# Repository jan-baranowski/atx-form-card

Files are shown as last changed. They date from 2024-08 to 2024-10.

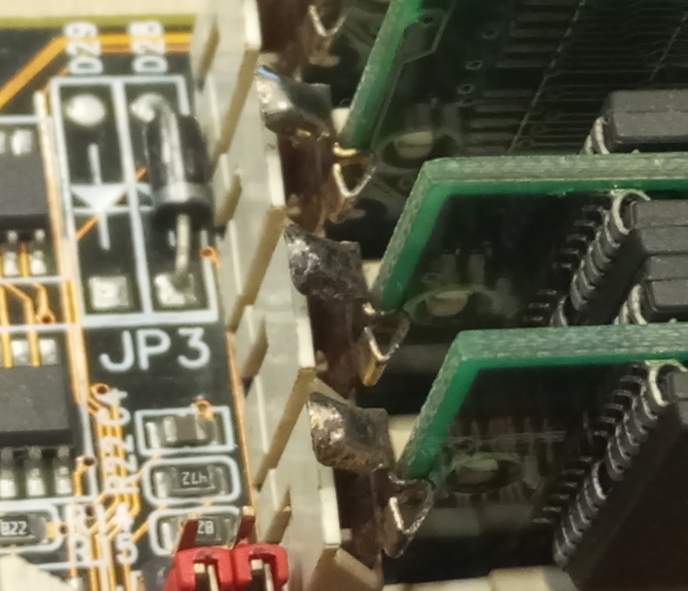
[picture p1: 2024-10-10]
doc/blogpost/img/IMG_20241010_175703.jpg

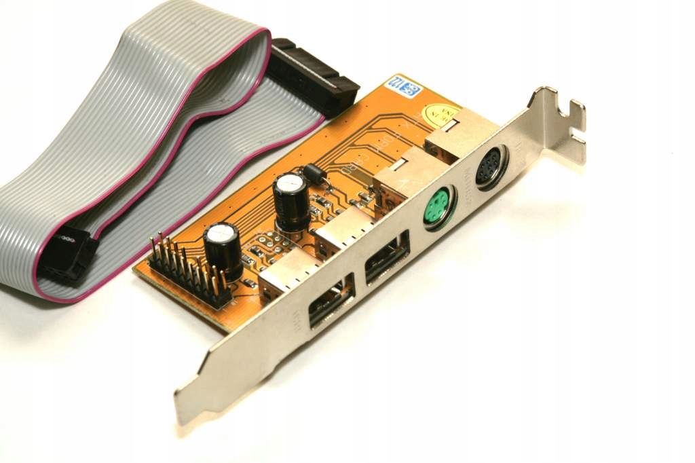
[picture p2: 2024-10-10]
doc/blogpost/img/06745c53491888d843a4edbb89a4.jpg

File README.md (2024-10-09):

ATX Form Card
=============

This is the repo containig project files, production files and documentation for an ATX Form Card - USB+IrDA+PS/2 bracket to be used in late AT motherboards produced by PCChips and ASUS ca. 1997.

Complete description of this project can be found at https://patoelektronika.blogspot.com/2024/10/atx-form-card.html

All the work that is not a third party documentation or libraries is licenced under WTFPLv2.

Third-party items incorporated
------------------------------

1. ATX Form Card reverse engineering attempt by Jacek Głogowski - /doc/glogowski.pdf - https://jacek.unixstorm.org/elektronika/atx-form-card.html
2. mini DIN EAGLE library - /hw/atx_from_card/mini_din.lbr - https://forums.parallax.com/discussion/124010/what-is-the-ps2-connectors-name-in-the-eagle-lib
3. polygon version os Open Source Hardware logos library for EAGLE - /hw/atx_from_card/oshw_custom.lbr - Andrew Cooper, http://www.darkerview.com
4. documentation on using HP C4103a IR transceiver with ASUS motherboards - /doc/irda/* - http://www.colin99.co.uk/extras/irda/hp_c4103a_irda.htm and https://www.infrarotport.de/mobo/asus_ir.htm
5. documentation on audio bracket, a companion to ATX Form Card - /doc/25-pin-sound-game-ribbon-cable - https://retrocomputing.stackexchange.com/questions/25069/25-pin-sound-game-ribbon-cable

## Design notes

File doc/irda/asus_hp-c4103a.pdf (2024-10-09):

Diese Seite führt da weiter, wo die Anregungen von Andreas Schüßler (https://www.infrarotport.de/mobo/asus_ir.htm) endeten.

Anschlußbelegung der ASUS-Infrarotschnittstellen und des IrDA-Moduls (C4103A) von Hewlett-Packard.

Die meisten Asus-Boards sollten folgenden Pfostenstecker aufweisen (verbindlich getestet mit P5A und P2B):

Den Anschluss FIR-RxD können wir zu diesem Zwecke getrost vergessen.

Daniel Eggel hat etwas intensiver geforscht und im Web bei HP die Belegung des HP-Steckers gefunden: HP-C4103A (https://www.infrarotport.de/mobo/c4103A2.PDF) (Stammt ursprünglich von folgender Seite: Hewlett-Packard). (http://www.hp.com/)
Steckerbelegung von vorne, also nicht die Lötseite!
PIN Number | Signal Name
1 (Indicator LED) | -SIGNAL_DETECT
2 (single-ended signal) | -RX_SIR
3 (Differential data) | -TX (Transmit Data)
4 (Ground) | PWR_GND
5 (FIR differential data) | -RX_FIR
6 (Differential data) | +TX (Transmit Data)
7 (5 volt power) | +5V_POWER
8 (FIR differential data) | +RX_FIR

Diese Pinbelegung ist offensichtlich nicht kompatibel zu einer bereits vorhandenen 8poligen ASUS-Standard-Buchse! (Erinnern wir uns an die mahnenden Worte von Andreas Schüßler). (https://www.infrarotport.de/mobo/asus_ir.htm)
Schließt man die HP-IrDA C4103A an das ASUS-Board an, so brennt sofort die Sicherung auf der Buchsenplatte durch. Zum Glück ist da eine drauf! Denn die Betriebsspannung von 5V wird mal eben kurzgeschlossen.

Dies bedeutet also Lötkolben anwärmen und umlöten (Lötkolben wird sowieso noch gebraucht)!

Leider besitze ich noch keine solche Buchse zum selbstlöten, weshalb ich auf ne fliegende Verkabelung ausgewichen bin. Hier aber ein paar Buchsen (incl. Herstellerbezeichnungen), gefunden auf den Seiten der Infrared Data Association: (http://www.irda.org/standards/pubs/IrDA_Dongle_V1p2.PDF)

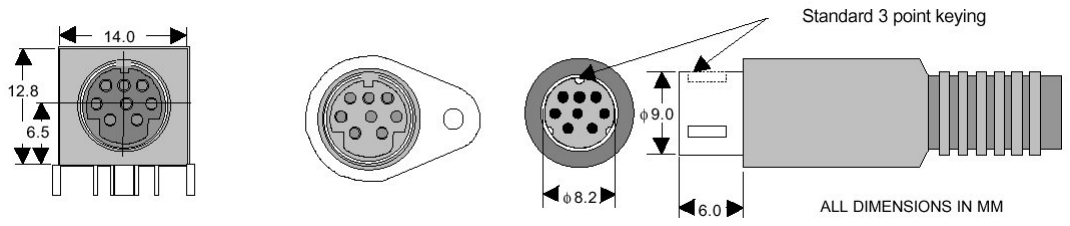
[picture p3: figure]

AMP | 750338-1
Maxconn | MMDV-8
Singatron | YE-1368A
CUI Stack | SD-80SN

Mit diesem Wissen bewaffnet, funktioniert die ganze Geschichte aber leider noch nicht ganz.
Der Rechner erkennt zwar (richtigen Anschluss vorrausgesetzt), dass etwas empfangen werden soll, jedoch kann der Rechner selbst nichts senden.
Schuld daran sind die differential TX Anschlüsse (RX ist single-ended) des HP Modules.
Die Asus-Boards können TX und RX leider nur single-ended.

Dadurch lassen wir uns aber nicht abschrecken.

Nach einigem Probieren studierte ich Dschen Reinecke's (https://www.infrarotport.de/ir-modul.HTML) Bauanleitung, was mich dazu bewog, den im HP-Modul eingebauten IR-Transceiver (HSDL-1100) genauer unter die Lupe zu nehmen.

Fündig geworden bin ich bei Agilent Technologies Inc. (http://www.semiconductor.agilent.com/ir/hsdl1100.html)

HP-IrDA C4103A an Asus Mainboards Infrarotprojekt | https://www.infrarotport.de/mobo/asus_hp-c4103a.htm
1 z 2 | 09.10.2024, 17:49

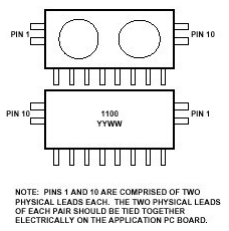
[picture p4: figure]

Pin | Description | Symbol
1 | PIN Bypass Capacitor | CX1
2 | Ground (Analog) | GND
3 | Averaging Capacitor | CX4
4 | Supply Voltage | VCC
5 | Receiver Data Output – Channel B | RXD-B
6 | Ground | GND
7 | Transmitter Data Input | TX
8 | Receiver Data Output – Channel A | RXD-A
9 | Threshold Capacitor | CX3
10 | LED Anode | LEDA

Pin 7 bietet ein single-ended TXD, was also lag näher, als diesen Pin mit dem entsprechenden Pin auf dem Mainboard zu verbinden.

Man nehme einen feinen Kreuzschlitz Schraubendreher und öffne das HP-Modul.
Von dem HP-Modul sind mir 2 verschiedene Varianten untergekommen, eines ist mit 4 Schrauben, das andere nur mit 2 Schrauben verschraubt. In jedem Fall muss der Aufkleber auf der Unterseite entfernt werden, darunter findet man 2 Schrauben.
Bei dem 4 Schrauben Modell befindet sich jeweils noch eine Schraube unter den kleinen runden Gerätefüssen.

Legt das Modul so vor Euch hin, dass der Transceiver zu Euch zeigt, das Anschlusskabel von Euch wegzeigt.

Nunmehr eine kleine Drahtbrücke zwischen Pin 7 des IR-Transceivers und der Anschlussleitung ganz links (meist rosa)
einlöten, Modul wieder zusammenschrauben!
Damit steht uns an Pin 1 des Steckers das single-ended TX-Signal zur Verfügung.

Jetzt noch das Anschlusskabel des IR-Modules mit der Pfostenleiste des Mainboards verbinden (bei mir in fliegender Verkabelung). .
Mainboard | 8poliger Stecker am HP-Modul
+5 Volt | Pin 7 (VCC)
IR-RxD | Pin 2 (-RX_SIR)
GND | Pin 4 (GND)
IR-TxD | Pin 1 (-SIGNAL_DETECT)
Die Anschlüsse für Fast-Infrared, sowie die differential bleiben jeweils frei.

Viel Spass beim Nachbau!
Fragen per Mail an mich.
Ach ja, keinerlei Garantie für evtl. Hardwareschäden!!!!!!
HP-IrDA C4103A an Asus Mainboards Infrarotprojekt | https://www.infrarotport.de/mobo/asus_hp-c4103a.htm
2 z 2 | 09.10.2024, 17:49

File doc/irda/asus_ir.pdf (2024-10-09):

# Willkommen, Bastler!

Diese Seite setzt auf das dankenswerterweise von Dschen Reinecke (https://www.infrarotport.de/kontakt.HTML) entwickelte und ins Netz gestellte Infrarotport-Selbstbauprojekt (http://www.infrarotport.de/) auf. Genaugenommen ist diese Seite nichts anderes, nur für ein ASUS-Motherboard (http://www.asus.com/) TX97-E durchgespielt. Diese Seite wurde wegen einiger Problemchen bei der Inbetriebnahme am Asus-Board erstellt.

Gemeinerweise | unterscheidet | sich | die
Anschlußbelegung | einer | | ASUS-

## Infrarotschnittstelle von der einer Hewlett-

Packard.

Nochmal für alle:

## Do not connect an HP C4103A directly to any ASUS mainboard!!! If you want to do so, look at the pages of Ralf Probst. (https://www.infrarotport.de/mobo/asus_hp-c4103a.htm)

Schließt man die HP-IrDA C4103A an das ASUS-Board an, so brennt sofort die Sicherung auf der Buchsenplatte durch. Zum Glück ist da eine drauf! Denn die Betriebsspannung von 5V wird mal eben kurzgeschlossen.
Update 1:
Daniel Eggel hat etwas intensiver geforscht und im Web bei HP die Belegung des HP-Steckers gefunden:
HP-C4103A (https://www.infrarotport.de/mobo/c4103A2.PDF) (Stammt ursprünglich von folgender Seite: Hewlett-Packard (http://www.hp.com/) ).

Das Board TX97-E von Asus ist serienmäßig für eine IrDA-Schnittstelle (http://www.irda.org/) vorbereitet. Sie kann auf 2 Arten angeschlossen werden:

1.: Mit dem Original - PS/2 Mouse, USB, Infrared Connector von ASUS, kostet etwa 35,-- euro.

Dies ist ein Slotblech mit einem Stück Leiterplatte, auf der die o.g. Buchsen montiert sind. Es wird wie ein normales Slotblech in den PC geschraubt. Ein mitgeliefertes Flachkabel mit Stecker paßt genau auf die Schnittstelle neben dem obersten PCI-Steckplatz. Eine der Buchsen darauf ist die IR-Buchse, die wie folgt beschaltet ist:

Asus TX97-E Infrarotprojekt von Andreas Schüßler | https://www.infrarotport.de/mobo/asus_ir.htm
1 z 3 | 09.10.2024, 17:48

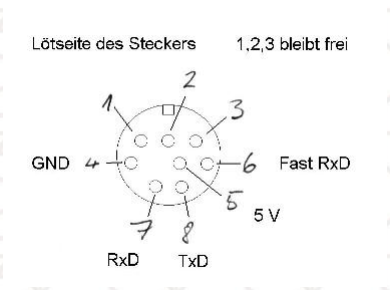
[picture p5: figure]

2.: Direkt auf einem der beiden Pfostenstecker. Hier ist der dargestellt, der der Vorderseite des Rechners zugewandt ist.

Die Anschlüsse für Fast-Infrared bleiben jeweils frei.

Die Datenübertragung über IrDA ist eine serielle. Das ASUS-Board TX97-E benutzt dafür den UART2-Baustein. Das muß im Bios (bei mir ist es das Award Bios v4.51PG) eingestellt werden:

Mit Del bzw. Entf während des Systemstarts ins Bios gehen, dort zur Seite CHIPSET FEATURES SETUP wechseln. Die seriellen Ports habe ich folgendermaßen konfiguriert:

ONBOARD SERIAL PORT 1 3F8H / IRQ 4
ONBOARD SERIAL PORT 2 2F8H / IRQ 3
UART2 USE INFRARED ENABLED

Die Infrarotschnittstelle läßt sich nur auf COM 2 legen. Der ONBOARD SERIAL PORT 2 darf daher nicht disabled werden. Die COM 2-Schnittstelle steht also ab jetzt nicht mehr zur normalen Verfügung.

Nun folgt die Installation im Betriebssystem, wie bei Dschen Reinecke (http://www.infrarotport.de/) beschrieben.

Wenn das alles erfolgreich war, kann man sich an den Aufbau wagen.

Ich mußte einen unverhältnismäßigen Aufwand in Sachen Abschirmung treiben. Abgeschirmtes Kabel, Siebung der Betriebsspannung (siehe Troubleshooting-Seite von Dschen Reinecke) (http://www.infrarotport.de/troubleshooting.HTML) und ein abgeschirmtes Gehäuse waren notwendig. Das festzustellen war das eigentliche Problem. Riesige Störungen entstanden durch bloßes Annähern an den IrDA-Baustein. Die Störungen kann man aber nur mit einem Oszilloskop feststellen. Dazu muß man wissen, daß das Sendesignal auf der TxD-Leitung High-aktiv ist, das Empfangssignal auf der RxD-Leitung dagegen Low-aktiv. ;-) Beides sind TTL-Pegel. Das Verbinden von TxD und RxD bringt also anders als bei einer normalen Schnittstelle in einem Terminalprogramm kein Echo hoch.
Update 2:
Mittlerweile weiß ich, woher die massiven Einstreuungen kommen: Eine unglaublich vermurkste Netzspannung bei mir im Haus. Mit Sinusform hat das wenig zu tun. Außerdem kann ich zwischen dem PC-Gehäuse und der Heizung einen Tauchsieder betreiben...

Ich wünsche allen viel Erfolg beim Nachbau! Bei Fragen zu DIESEM AUFBAU stehe ich gerne per email an Andreas Schüßler zur Verfügung. Alternativ kann auch Dschen Reinecke per Mail (https://www.infrarotport.de/kontakt.HTML) kontaktiert werden.
Wer Fragen dazu hat, wie man ein HP C4104A doch an ein ASUS-Bord anschliesst, wende sich an Ralf Probst. (http://www.infrarotport.de/mobo/asus_hp-c4103a.htm)

Update 3:
Disclaimer (oder wie das heisst):
Ach ja, sollte sich irgendjemand wegen dieser Seite auf den Schlips getreten fühlen, möchte er sich bitte mit MIR und nur mit MIR in Verbindung setzen. Selbstverständlich gehören Markennamen dem jeweiligen Eigentümer, es liegt mir fern, daran zu kratzen. Im Falle von Unterlassungsklagen oder Ähnlichem: Ich bin Student, bei mir ist nichts zu holen.

Update 4:
Mittlerweile bin ich kein Student mehr, zu holen ist aber trotzdem nix.

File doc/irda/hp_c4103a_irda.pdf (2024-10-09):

# Convert an HP C4103A Infra red module for use as a PC IrDA

port.

The C4103A infra red module is intended for adding IrDA communications to certain Hewlett Packard printers which don't already have this facility built into them. These modules are often left lying around the office unused, and as such can be picked up for next to nothing and slightly modified to act as an IrDA port for your PC. It will only be of use if your motherboard has a IrDA connector, which most do.

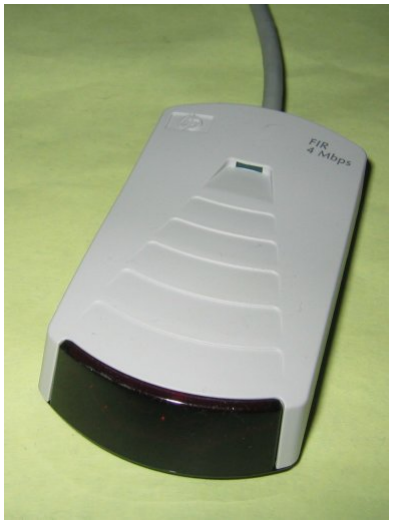
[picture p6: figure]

I take no credit at all for the technical aspects of working out the necessary modifications, they are all down to the following two web pages:

http://212.188.112.5/kengaru/index.php

http://www.infrarotport.de/mobo/asus_hp-c4103a.htm

Now unless you are very good at German and Russian, you will have spotted the problem with those pages. So I am simply setting out what you need to do to achieve the result of being able to use the C4103A module with a standard modern motherboard which has an IrDA connector. I recommend looking at the above two pages for extra information which I don't necessarily supply here. The latter one will go through the Google translator to give a fairly readable page. (http://216.239.35.120/translate_c?hl=en&sl=de)

Typically, the connector will have the following pinout. This certainly applies to Asus and Abit motherboards, so is likely to be reasonably standard:

The cable of the HP C4103A is an 8 pin mini-Din connector, and has most of the functions we require, but not the single ended TxD (transmit data) required:

Pin Number | Signal Name | Typical wire colour
1 | (active high input) -SIGNAL_DETECT | Pink
2 | (single-ended driver) RX_FIR | Green
3 | (TP, pins 3 and 6) -TX (Transmit Data) | Light blue
4 | (TP, pins 4 and 7) PWR_GND | Yellow
5 | (Receive Data Gnd) -RX_FIR | White
6 | (pulse = data 0) +TX (Transmit Data) | Orange
7 | +5V_POWER | Purple
Convert an HP C4103A Infra red module for use as a PC IrDA port | http://www.colin99.co.uk/extras/irda/hp_c4103a_irda.htm
1 z 5 | 09.10.2024, 17:53

8 | (pulse = data 0) +RX_FIR | Black

8 Pin Mini-Din Plug

This is the plug pin view of the mini-Din plug.

2 | 1
+ | +
5+ +4 | +3
| + + + 8 7 6

As the above web links show, we need to make a small wiring change to add the required signal, from a point connected to pin 7 of the IR transceiver unit, to the pink wire from the unit. The first, surprisingly tricky thing to do is open the C4103A unit. There are probably four screws holding it together, though you won't see any of them! Two hide under the small rubber feet at the cable end of the module, the other two under the large black label in very offset positions.

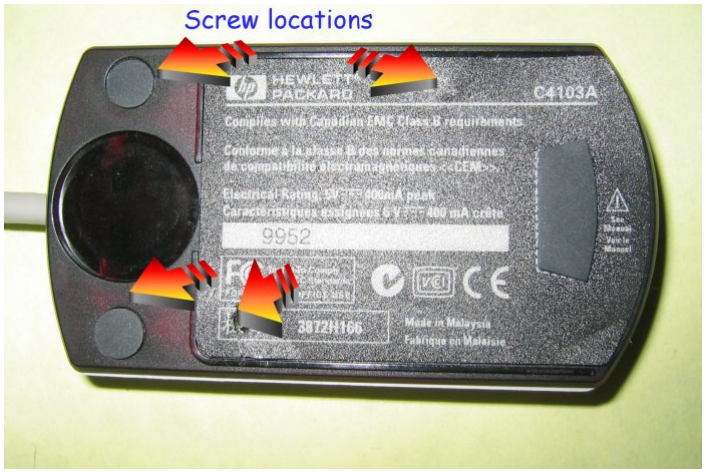
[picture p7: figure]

Remove these, take the unit apart, carefully noting how the cable support has notches in one side which sit in grooves of the case when re-assembled. Some units have different screw positions and quantities, some have different wiring colours, and some have a different PCB payout such that you may need place your wire in a different position (see later).

Solder a wire as shown, from the resistor RX1 (end towards IR module):

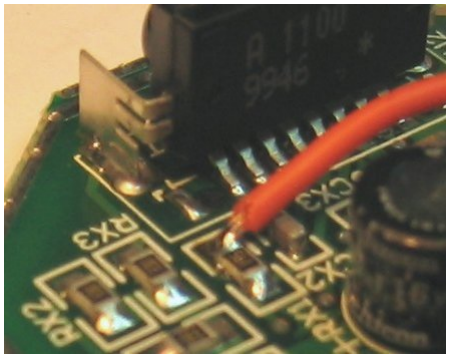
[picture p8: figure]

Run the wire down to the underside of the PCB, connector pin1 (typically a pink wire). If you wish to carry on also using the module for its intended application with HP printers, you should find space to fit a small toggle switch so that you can isolate the new wire. Most people don't wish to do this and simply run the wire as shown:

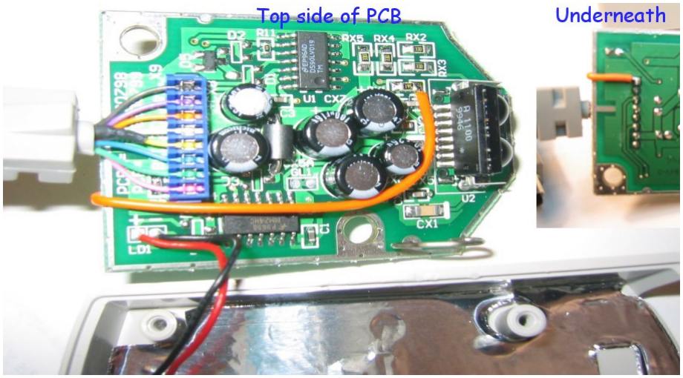
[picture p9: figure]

We have not disconnected the existing circuitry connected to pin 1 of the PCB. Since this is an input to the green LED on the HP C4103A, we are allowing this LED to illuminate whenever data is transmitted.

Here we have an alternative version of the module. It has only 2 screws (under the info label at exact same spots as the version above), no foil shielding, and the PCB has a different layout. The mod is to solder a wire (here a white one) from the RX1 resistor (at the side of the IR transceiver) to PIN 1 of the JP2 header (which is marked with a white square). Information kindly supplied by "fossalta (at) xs4all (dot) nl".

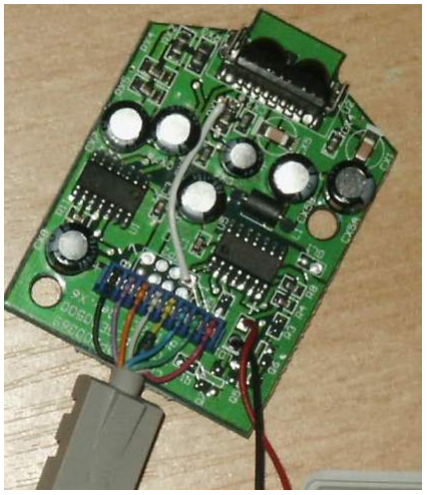
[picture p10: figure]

Reassemble the unit. Now you have the problem of connecting to the motherboard. You have a choice here. You can buy a 8 pin mini-Din panel mount socket from RS Components etc, and carefully mount this into a blanking plate for the back of your computer. Then wire the pins thus, from a 5 pin female header connector to the back of the 8 pin mini-Din socket:

Mini Din Pin Number | Signal Name | Motherboard header pin
1 | Now our TxD pin | 5
2 | Rxd | 3
3 | | -

4 | GND | 4
5 | | -
6 | | -
7 | +5V_POWER | 1
8 | | -

RS Components (http://www.rswww.com/) do the sockets, in multiples of 5, part number 183-1805, and pins for them are 183-1811 in multiples of 10. If, like me, you thought it too expensive to source an individual 8 pin mini-Din socket, then use an alternative connector. I chopped off the 4103A plug, and wired it instead to a 9 pin D connector plug, pin for pin, and also connected the cable screen to the plug body. I then found a scrap ISA card with a convenient end plate already punched out for this size of connector, i.e. an old graphics card. I stripped off the PCB leaving me with just the end panel, onto which I fitted a 9 pin D connector socket, and performed the same wiring as above.

My first attempt at making it run was a flop, because Abit didn't make it terribly obvious which was pin 1 of the IrDA connector. Once this was correct, we could start on the software. I told the BIOS to enable the IrDA port as HPSIR rather than ASKIR (latter didn't work). This also had the unfortunate consequence of disabling the COM2 serial port. Then I let Windows XP detect the IR port. Now if I put my horrible little Compaq LTE5100 laptop in front of the HP C4103A module, the green light on the module would flash, and the two machines announced that they were within range of each other ("Colin's laptop is in range" and "Colin's XP1600 is in range", which are the machine names).

Settings

I came unstuck in terms of real data transfer between the two at this point, because XP can only install a network with another PC which runs Windows 98 SE or later, and my old laptop was stuck on Windows 95 SE due to a lack of memory. No doubt I could install the necessary networking manually on the laptop but that was starting to be hard work. The laptop however can also print to my HP Laserjet 6P printer via IrDA, and program a Nokia 5210. But when the printer was put in front of the C4103A, though the LEDs flashed, Windows XP did not report hardware was in range. Neither would Windows XP see the Nokia phone. So ultimately, though I had got the system to work to some extent with the laptop, I was unable to get the important stuff to work. Perseverance paid off though, I went back to PC's setup BIOS and selected Half Duplex type HPSIR, and hey presto, communications were established with Nokia 6100 and 5210 phones. Limiting connection speed to 19200baud in Windows XP settings helped reliability hugely. So in conclusion, I would recommend using the following parameters:

Setting type | Version I had | Value | As opposed to
BOIS setting: IR port | Abit / Award | HPSIR | ASKIR
BIOS setting: Duplex | Abit / Award | Half Duplex | Full Duplex
Windows Irda port setting: Maximum connect rate | Windows XP | 19200 baud | 115200

A reader of this article told me: "The device worked. My BIOS setting was set to IrDA, as ASKIR did not work. I don't have a setting for half duplex/full duplex. Not only that, the connect rate worked on 115200, 57600 and 19200 baud. I used Logomanager to upload logo, ringing tone and screensaver on my Nokia 5210 using the different baud mentioned. My system is ECS K7S5A motherboard, AMD Athlon 1000, Windows XP."

Another reader reported "In the BIOS I have the following options: RxD/TxD = Hi/Lo , Rx/Tx= Lo/Hi , Rx/Tx=Lo/Lo and Rx/Tx=Hi/Hi. It only works with setting Rx=Lo" So different settings are worth experimenting with if you find that communications are unreliable or you get strange errors. Another reader says "It works at 115200 bps on a Asus A7V333, Windows XP".

Another reader again, uses one with the following motherboard: MSI K7N2 Delta. Settings:
UART mode - IrDA
RxD/ TxD - Lo, Hi
IR Transmission Delay – Disabled
UR2 Duplex - Half
Use IR pins - IR-Rx2Tx2
Speed (WinXP) - 19200
Works great with Nokia 6200 with its transfer software

Another reader had a problem with the adapter getting hot, but found a solution in the BIOS: "In my award bios there's an entry : TX,RX Inverting Enable, with 4 options [no-no; no-yes; yes-no; yes-yes]. RX MUST be set to yes to let adapter work on winXP. What I have found is that when RX inverting is enabled, the adapter works the same way it does when is not enabled, BUT the irda bulbs get very very warm. So,bios settings for me are NO-YES It's a terrible AZZA 694TXL :) I use it for ordinary work, P3 600 Mhz (socket 370) 2x256 ecc sdram On winXp sp2 I can make the adapter work at 57600bps (!) In bios, HPSIR and HalfDuplex as you suggested on your webpage "

For now, I hope you find this information helpful. DISCLAIMER: Colour codes shown may vary. No responsibility is accepted for any damage caused, if you wish to try this experiment then it is entirely your own responsibility. You will need to be competent at soldering and fine work. THIS INFORMATION IS SUPPLIED AS-IS, NO RESPONSIBILITY IS ACCEPTED FOR ANY CONSEQUENTIAL DAMAGE, LOSS, INJURY OR MISHAP, HOWEVER CAUSED. Do not start to dismantle any equipment unless you are certain you are capable and have an understanding of electrical safety.

USB

I've had a number of emails asking if the HP C4103A module could be adapted for use with USB, and I have to say that this really would be far too much like hard work. Instead, buy a ready-built USB to IrDA adaptor from the good people at SVP communications, (http://svp.co.uk/products-solo.php?pid=404) for around

£12.69, their part number "5055", I use one of these with my latest laptop.

SVP
Communications
- The Shop (http://www.svp.co.uk/)

Colin McCormick, colin99@bigfoot.com September 2006.

Back to my web pages. (http://www.colin99.co.uk/)

Total site visitors since Jan 2005:

## See my video to DVD copy service, offering

transfers of Betamax, VHS, S-VHS, Video2000,Video8, Hi8, Digital8,

## miniDV,micromv, Betacam, N1500, N1700 and more: www.video99.co.uk

## The most affordable and flexible video tape to DVD transfer service in the UK. A personal service by an engineer with years of video

experience.

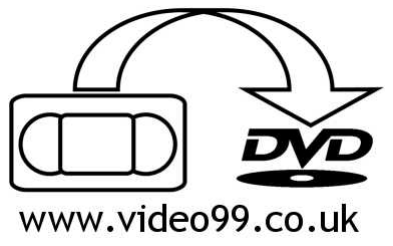
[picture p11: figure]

Sponsored links:

Ustawienia dotyczące prywatności i plików cookie
Zarządzana przez Google. Zgodność z zasadami TCF organizacji IAB. ID plaormy: 300

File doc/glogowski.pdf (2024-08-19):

## Schemat ATX FORM CARD do płyt głównych PC CHIPS

Poniżej zamieszczam schemat ideowy dodatkowego śledzia do płyt głównych PC CHIPS. Bardziej znana nazwa to ATX FORM CARD. Na ślediu tym znajdują się dwa porty USB, port PS/2 dla myszy i coś podobnego do PS/2 ale dla IRDY. Zamieściłem ten schemat ze względu na to, iż nie jest go łatwo znaleźć (ja nie znalazłem) a niektórzy (np. ja) posiadają jeszcze takie płyty i chętnie dodali by do nich wymienione powyżej porty. Wbrew pozorom łatwo zrobić taką karte nawet na tzw. pająka. A wygląda to tak.

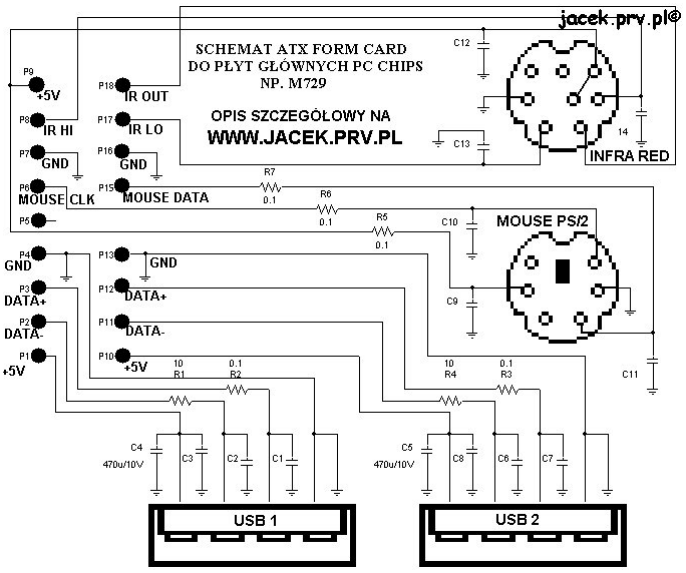
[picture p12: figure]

Na pierwszy rzut oka schemat może trochę przestraszyć (szczególnie jeśli nie interesujesz się zbytnio elektroniką), lecz tak naprawdę to tylko odpowiednio poprowadzone kabelki i już. Jeżeli chcemy to możemy praktycznie pominąć wszystkie elementy elektroniczne (rezystory i kondensatory), ale musimy liczyć się z tym, że może to się odbić na niezawodności i bezpieczeństwie dla układów na płycie głównej. Tak więc warto włożyć ciut więcej pracy i wykonać to tak jak na oryginalnej karcie (bo na niej się wzorowałem). Potrzebujemy do tego 2 kondensatory elektrolityczne 470u/10V, 13 kondesatorów ceramicznych o pojemności około 56p, 2 rezystory 10 Ohm i 5 rezystorów 0.1 Ohm. Najprościej mówiąc kondesatory filtrują i stabilizują a rezystory zabezpieczają przed zbyt dużym prądem. To teraz najgorsze, jak to wszystko połączyć i gdzie to podłączyć. Żeby było łatwiej będe umieszczał schemat ideowy a tuż pod nim zdjęcie jak to wygląda na "żywca". A więc cały ten schemat ideowy to jest to coś

Jacek Głogowski - strona prywatna | https://jacek.unixstorm.org/elektronika/atx-form-card.html
1 z 3 | 16.08.2024, 01:21

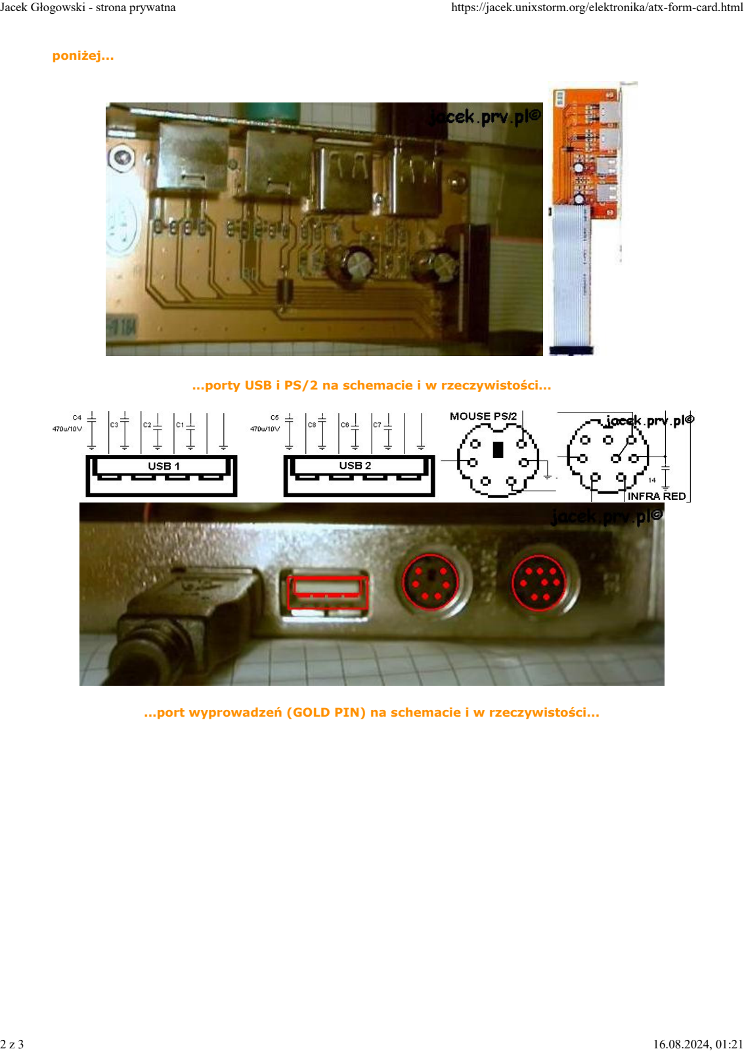
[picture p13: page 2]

poniżej...

...porty USB i PS/2 na schemacie i w rzeczywistości...

...port wyprowadzeń (GOLD PIN) na schemacie i w rzeczywistości...

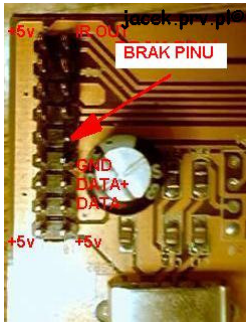
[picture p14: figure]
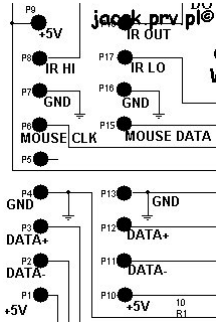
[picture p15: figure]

...identyczny port powinien znajdować się gdzieś na płycie głównej. Kabelek bez żadnych przeplotów, po prostu 1 do 1, 2 do 2, 3 do 3 i tak aż do 18 wyprowadzenia. To co zaznaczyłem na czerowno powinno ułatwić zorientowanie się gdzie co jest i co jest do czego. Jeżeli będziecie wykonywać tą kartę to zwróćcie szczególną uwagę na wyprowadzenia +5V i GND. NIE WOLNO ICH POMYLIĆ, zamienić miejscami, podłączyć gdzieś indziej. Może to zaskutkować zniszczeniem układów na płycie głównej lub/i urządzenia które podłączysz. Jeżeli zamienisz miejscami takie sygnały jak DATA+ i DATA- od USB to nic się nie stanie, po prostu nie zadziała, trzeba zamienić mniejscami kabelki i po kłopocie. Podobnie z przewodami sygnałowymi dla PS/2 lub IRDA, ale nie z przewodami zasilającymi. Jeszcze raz powtarzam NIE POMYL +5V i GND. Jeżeli będziemy wykonywać kabelek łączący naszą kartę z płytą główną, to warto zwrócić uwagę na brak jednego z pinów w porcie na płycie i na karcie ATX. Znajduję się on dokładnie na środku i ma numer 14 (patrz rysynek i zdjęcie wyżej), ułatwi to nam orientacje i zapobiegnie pomyłce przy podłączeniu. Gdy już mamy wszystko gotowe to najpierw instalujemy sterowniki od USB (niestety jak coś źle zainstalujemy to praktycznie możemy pożegnać się z sytemem, lepiej zrobić kopie całego katalogu WINDOWS lub przynajmniej SYSTEM), nastepnie włączamy w BIOSie obsługę USB, PS/2 i IRDE, sprawdzamy czy port zostały wykryte i czy nie ma konfliktów. USB powinno zostać wykryte jako osobna gałąź, a port PS/2 tylko gdy podłączymy pod niego mysz (w gałęzi myszki). Natomiast IRDA w przypadku mojej płyty M729 to już sprawa do Archiwum X, nie chce działać i już, nie ma w BIOSie, sterowniki nic nie dają. Może aktualizacja BIOSu coś pomoże, jak dojdę co i jak to napiszę. To życzę powodzenia przy wykonywaniu a gdyby pojawiły sie jakieś problemy (lub
napisałem coś niezrozumiale) to możecie pisać | .

POWRÓT

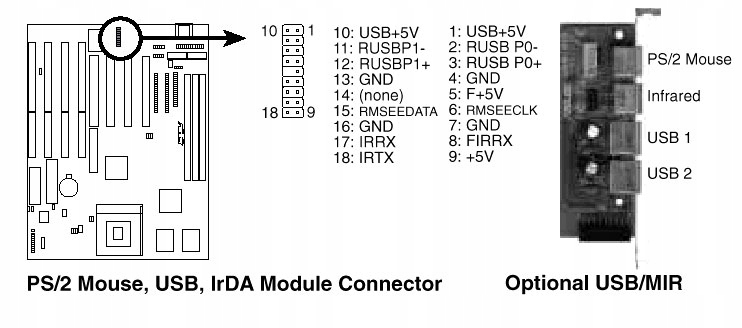
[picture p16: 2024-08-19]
doc/pinout.jpg

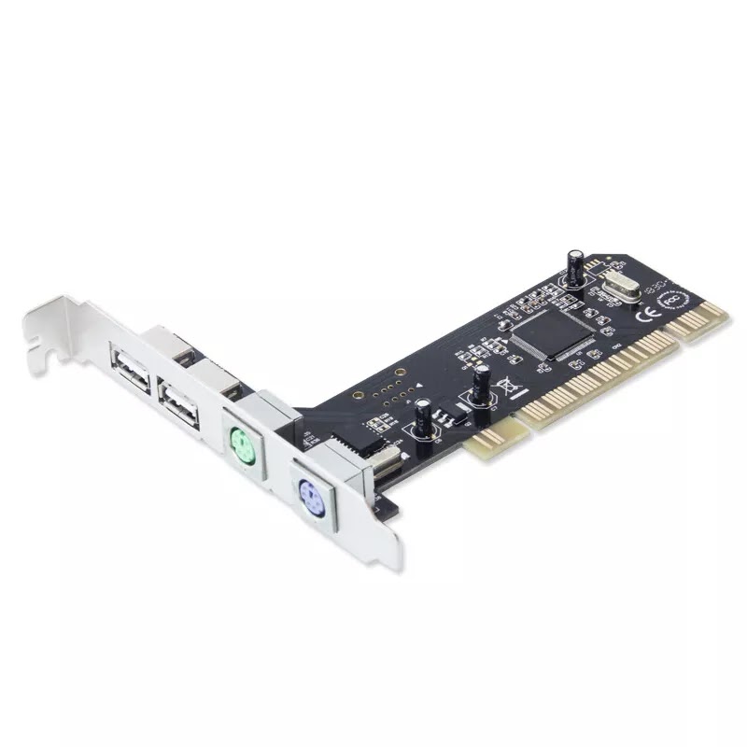
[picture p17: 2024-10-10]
doc/blogpost/img/s-l1600.jpg

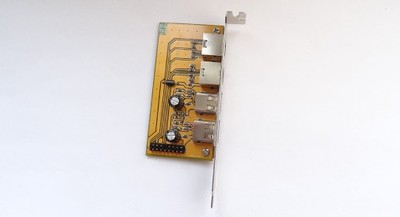
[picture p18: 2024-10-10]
doc/blogpost/img/dc3e6fab70c16257ae613c7f182c7a5ad2b294ec671bfa04050a5acf4d0a5f5a.jpg

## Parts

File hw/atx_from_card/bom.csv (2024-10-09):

Name | Value | Package | Manufacturer | MPN
C1 | 56p 50V 5% C0G | C3216 | WALSIN | T-24f190742
C2 | 1u 50V X7F | C3216 | Samsung | CL31B105KBHNNNE
C3 | 56p 50V 5% C0G | C3216 | WALSIN | T-24f190742
C4 | 56p 50V 5% C0G | C3216 | WALSIN | T-24f190742
C5 | 56p 50V 5% C0G | C3216 | WALSIN | T-24f190742
C6 | 56p 50V 5% C0G | C3216 | WALSIN | T-24f190742
C7 | 1u 50V X7F | C3216 | Samsung | CL31B105KBHNNNE
C8 | 56p 50V 5% C0G | C3216 | WALSIN | T-24f190742
C9 | 56p 50V 5% C0G | C3216 | WALSIN | T-24f190742
C10 | 56p 50V 5% C0G | C3216 | WALSIN | T-24f190742
C11 | 56p 50V 5% C0G | C3216 | WALSIN | T-24f190742
C12 | 56p 50V 5% C0G | C3216 | WALSIN | T-24f190742
C13 | 56p 50V 5% C0G | M3216 | WALSIN | T-24f190742
EC1 | 470u 10V | E3.5-8 | GZZ | T-74627
EC2 | 470u 10V | E3.5-8 | GZZ | T-74627
F1 |  | 0207/10 | STAR ELECTRONIC/JANTEC | RH356008
FB1 |  | M3216 | MuRata | BLM31PG601SN1L
FB2 |  | M3216 | MuRata | BLM31PG601SN1L
FB3 |  | M3216 | MuRata | BLM31PG601SN1L
FB4 | 10 | M3216 | DRALORIC | D2520010R5%P5
FB5 |  | M3216 | MuRata | BLM31PG601SN1L
FB6 | 10 | M3216 | DRALORIC | D2520010R5%P5
IR1 |  | M_DIN8 | TE Connectivity | 1658998-1
JP1 | not populated | MA04-2
JP2 |  | MA09-2
PS1 |  | M_DIN6 | TE Connectivity | 5749180-1
USB1 |  | PN87520-S | Amphenol | 87520-0010BLF
USB2 |  | PN87520-S | Amphenol | 87520-0010BLF

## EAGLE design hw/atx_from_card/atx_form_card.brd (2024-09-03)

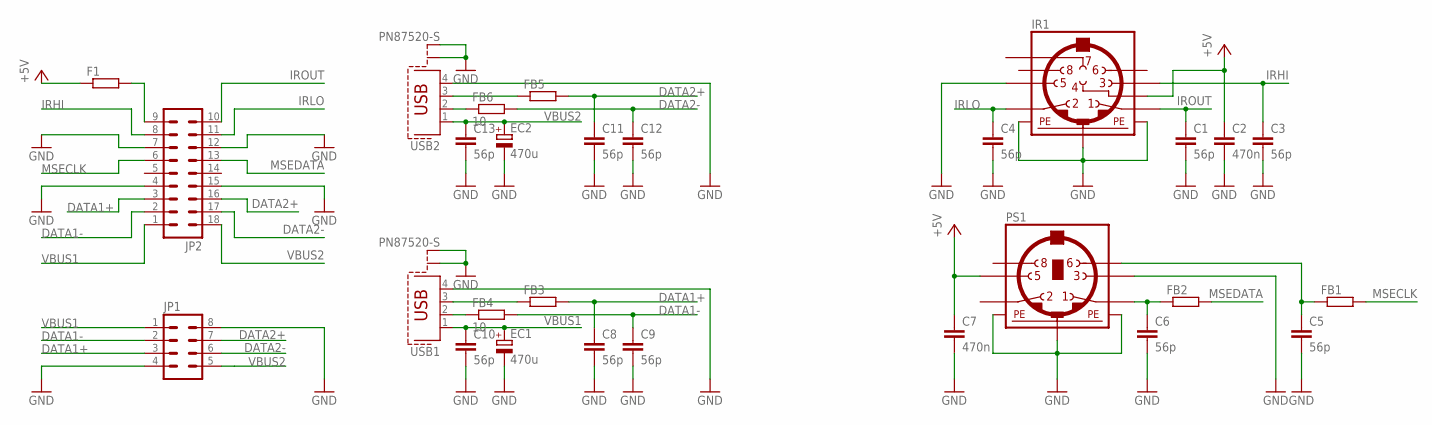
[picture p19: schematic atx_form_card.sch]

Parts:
C1, C3, C4, C5, C6, C8, C9, C10, C11, C12, C13: 56p; C3216
C2, C7: 470n; C3216
EC1, EC2: 470u; E3,5-8
F1: R-EU_0207/10; 0207/10
FB1, FB2, FB3, FB5: R-EU_M3216; M3216
FB4, FB6: 10; M3216
IR1: MINI_DIN_8; M_DIN8
JP1: MA04-2
JP2: MA09-2
PS1: MINI_DIN_6; M_DIN6
USB1, USB2: PN87520-S

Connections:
DATA1+: C8.1, FB3.2, JP1.3, JP2.3 (3_)
DATA1-: C9.1, FB4.2, JP1.2, JP2.2 (2_)
DATA2+: C11.1, FB5.2, JP1.7, JP2.16 (12_)
DATA2-: C12.1, FB6.2, JP1.6, JP2.17 (11_)
GND: C1.2, C2.2, C3.2, C4.2, C5.2, C6.2, C7.2, C8.2, C9.2, C10.2, C11.2, C12.2, C13.2, EC1.-, EC2.-, IR1.5, IR1.SH1 (PE1), IR1.SH2 (PE2), IR1.SH3 (PE3), JP1.4, JP1.8, JP2.4 (4_), JP2.7 (7_), JP2.12 (16_), JP2.15 (13_), PS1.3, PS1.SH1 (PE1), PS1.SH2 (PE2), PS1.SH3 (PE3), USB1.4, USB1.S1, USB1.S2, USB2.4, USB2.S1, USB2.S2
IRHI: C3.1, IR1.3, JP2.8 (8_)
IRLO: C4.1, IR1.2, JP2.11 (17_)
IROUT: C1.1, IR1.1, JP2.10 (18_)
MSECLK: FB1.2, JP2.6 (6_)
MSEDATA: FB2.2, JP2.13 (15_)
unnamed: FB4.1, USB1.2
unnamed: C6.1, FB2.1, PS1.1
unnamed: FB6.1, USB2.2
unnamed: FB3.1, USB1.3
unnamed: FB5.1, USB2.3
unnamed: C5.1, FB1.1, PS1.6
unnamed: F1.2, JP2.9 (9_)
VBUS1: C10.1, EC1.+, JP1.1, JP2.1 (1_), USB1.1
VBUS2: C13.1, EC2.+, JP1.5, JP2.18 (10_), USB2.1
VCC: C2.1, C7.1, F1.1, IR1.4, PS1.5

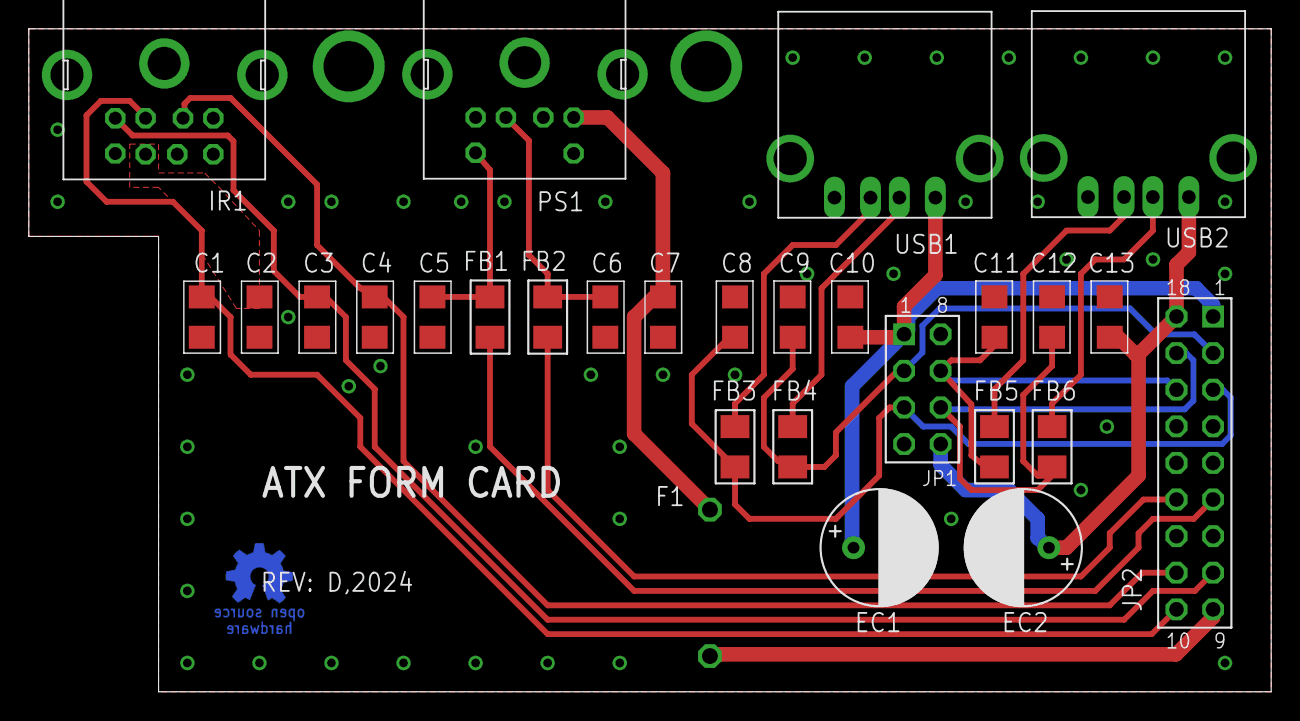
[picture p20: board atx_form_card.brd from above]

Board: 2 copper layers, 86.2 x 46.0 mm, 29 parts (1 on the bottom side), 20 nets.

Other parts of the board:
U$2: OSHW_5MM

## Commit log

2024-08-19 Schemat v1
    [atx_form_card.sch]
2024-08-22 Changed lstb library to match pin numeration convention to original. Added additional 4x2 pin USB connector. Changed component numeration to match original. Routed the board. Fixed .gitignore for boa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
    [atx_form_card.brd, atx_form_card.sch]
2024-09-03 Rev. D of the board. Added more documentation.
    [atx_form_card.brd, atx_form_card.sch]
2024-09-20 Added gerber files for rev. D
    [atx_form_card.drl]
2024-10-09 Added some additional documentation on IrDA transceiver to use with ATX Form Card and a companion audio bracket. Updated README.
2024-10-09 Added bill of materials.
    [bom.csv]
2024-10-10 Added current copy of blog article.
